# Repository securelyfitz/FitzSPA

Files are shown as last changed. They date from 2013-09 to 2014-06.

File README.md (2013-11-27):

FitzSPA
=======

Joe Fitz's Simple Power Analysis Tool

This is a simple board for monitoring power analysis of small microcontroller circuits.

See the slides from BsidesPDX here: http://goo.gl/m2waMq

## Changes
The major change in 1.1 is that there is now a 2nd potentiometer tied to the offset input of the amplifier. This allows you to dial in an offset so you can adjust to a larger differential gain without exceeding the input range of the A/D converter.

I thought i could get away without this in rev 1.0 but it has shown to be too important. Time will tell if a potentiometer is sufficient or i should have used a low impedance reference (at additional complexity, BOM cost, board space, and redesign time)

## Theory

The current across the shunt resistor Rv is measured with a differential amplifier U2. The output is digitized by the A-D converter, U1, which is triggered and synchronized by the device's own clock signal. The JP1 pins connect to a logic analyzer for sampling.

The differential amplifier will cancel out all sorts of common mode noise and only amplify the voltage across the Rv shunt resistor, which will be proportional to the instantaneous current draw of your target device. By synchronizing the A/D sampling to the device clock, we can get a digital readout at roughly the same time every clock cycle and not have to oversample 10x or more. Right now the Logic analyzer connection is asynchronous, but that should be fixed in future revisions.

Future versions will integrate a Cypress EZ-usb FX2 logic analyzer and power regulation, but they were excluded to reduce time and complexity for revision 1.x

##Using

Connect the logic analyzer to the J1 connector. Pin1 in the upper left is AD0, the LSB. The bottom two pins are both ground. If you have an 8-bit logic analyzer, start with the 8 MSBs, and if all of your sampling is in the same range, try connecting to less significant pins for higher gain.

Power +5vdc can come from a USB cable, an external supply, your logic analyzer, or from your target system

JP3 has a number of pins for various ways of connecting your shunt resistor and powering your target. Pins in order: VCC  Rv+  Rv-  GND  GND  CLK

To measure with a shunt on VCC, power supplied by FitzSPA:
* Connect VCC and Rv+ with a jumper
* Connect RV- to your target board's VCC
* Connect GND to your target board's GND
* Connect CLK to your target board's CLK

To measure with a shunt on GND, power supplied by FitzSPA:
* Connect VCC to your target board's VCC
* Connect Rv+ to your target board's ground
* Connect RV- and GND with a jumper
* Connect CLK to your target board's CLK

To measure with a shunt on VCC, with a separate external supply:
* Connect Rv+ to the external supply
* Connect RV- to your target board's VCC
* Connect GND to your target board's GND and external supply GND
* Connect CLK to your target board's CLK

To measure with a shunt on GND, power supplied by FitzSPA:
* Connect your external supply to the target board's VCC
* Connect Rv+ to your target board's ground
* Connect RV- and GND with a jumper
* Connect the second GND pin to the external supply's GND
* Connect CLK to your target board's CLK

Fire up your logic analyzer, turn on your board, and you should see the live power consumption updated each clock cycle!

##Building
Rev 1.1 is functional and continues to iron out some kinks. There are a few options for building out your board:

#### Differential Amplifier:
The AD8129 should provide much higher gains for more sensitive readings. However, I still haven't debugged why the AD8130 works fine and the AD8129 does not at G=10. For the time being, use the x30 unless you want to help the debug effort. the x29 is digikey AD8129ARMZ-ND
#### Gain setting circuit:
The gain of the differential amplifier is 1+(Rf/Rg). The default BOM uses 1k Ohm/100 Ohm, but you can vary this, or replace Rf with a potentiometer, such as digikey 987-1155-ND
####Voltage Regulator Load:
the 5v to +-12v regulator needs a minimum load to work properly. I haven't needed them, but populating R1 and R2 with 2.4k ohm resistors should provide the required load. digikey RMCF0603FT2K40CT-ND

####For the basic build you probably want:

Component | Description | Value | notes | Digikey | Price
--- | --- | --- | --- | --- | ---
U1 | AD9200ARZ | 20msps 10-bit A/D converter | | AD9200ARSZ-ND | 5.83
U2 | AD8130ARMZ | differential amplifier | AD8129 - unresolved issues. use AD8130 for now | AD8130ARMZ-ND | 4.06
U3 | VAT1-S5-D12-SMT | 5v to +-12v converter | | 102-1386-1-ND | 5.51
JP1 | 2x6 .1" header | | connects to LA | S1012EC-40-ND	| 0.51
JP2 | 1x3 .1" header | | connects ot power/ground | same as jp1 |
JP3 | 1x6 .1" header | | connects ot DUT | same as jp1 |
C1,C2,C3,C4,C5,C6,C7,C8 | 0603 SMT Capacitor | .1uF | | 587-1240-1-ND	| 0.10
C11,C12,C13,C14,C15,C16 | 0805 SMT Capacitor | 10uF | doesn't need to be electrolytic | 587-1295-1-ND | 0.25
R1,R2 | 0603 SMT resistor |  | leave empty unless needed to stabilize +-12v output |
R3 | 0603 SMT resistor | 150 ohm | LED series resistor | RMCF0603FT150RCT-ND | 0.04
R4 | 0603 SMT resistor | 10 ohm | provides a little isolation between digital and analog VCC | RMCF0603FT10R0CT-ND | 0.04
Rv | 0603 SMT resistor | 1 ohm | shunt resistor - DUT power crosses over this | RMCF0603FT1R00CT-ND	| 0.04 
Rg | 0603 SMT resistor | 100 ohm | gain resistor | RMCF0603FT100RCT-ND | 0.04
Rf1 | 0603 SMT resistor | 1k ohm | gain resistor | RMCF0603FT1K00CT-ND | 0.04
Rf | 84WR SMT Potentiometer |  | leave empty if using fixed Rf1 instead |
Rf2 | 84WR SMT Potentiometer |  | potentiometer for adjusting offset bluewire pin 4 to ground if you really don't want this |
LED | 0603 SMT LED | | | 475-2558-1-ND	| 0.09

The Digikey BOM is saved in FitzSPA-BOM.csv, you can upload or paste it's contents into the BOM wizard: https://www.digikey.com/classic/registereduser/BOMWizard.aspx

$18.50 + shipping

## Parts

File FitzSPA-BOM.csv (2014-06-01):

Digi-Key Part Number | Manufacturer | Manufacturer Part Number | Customer Reference | Quantity 1 | Quantity 2 | Quantity 3 | Description | Comments | RoHS Status | Lead Free Status | REACH Status
AD9200ARSZ-ND | ANALOG DEVICES INC | AD9200ARSZ |  | 1 | 0 | 0 | IC ADC 10BIT CMOS 20MSPS 28-SSOP | Alternate Packaging Exists | RoHS Compliant | Lead free | Unaffected May-2011
AD8130ARMZ-ND | ANALOG DEVICES INC | AD8130ARMZ |  | 1 | 0 | 0 | IC OPAMP DIFF 290MHZ 8MSOP | Alternate Packaging Exists | RoHS Compliant | Lead free | Unaffected May-2011
102-1386-1-ND | CUI INC (VA) | VAT1-S5-D12-SMT-TR |  | 1 | 0 | 0 | CONVERTER DC/DC +/-12V OUT 1W | Alternate Packaging Exists | RoHS Compliant | Lead free | Unaffected Oct-2011
S1012EC-40-ND | SULLINS CONNECTOR SOLUTIONS | PREC040SAAN-RC |  | 1 | 0 | 0 | CONN HEADER .100 inch SNGL STR 40POS |  | RoHS Compliant | Lead free | Unaffected Sep-2008
587-1240-1-ND | TAIYO YUDEN (VA) | EMK107B7104KA-T |  | 8 | 0 | 0 | CAP CER 0.1UF 16V 10% X7R 0603 | Alternate Packaging Exists | RoHS Compliant | Lead free | Unaffected Nov-2009
587-1295-1-ND | TAIYO YUDEN (VA) | EMK212BJ106KG-T |  | 6 | 0 | 0 | CAP CER 10UF 16V 10% X5R 0805 | Alternate Packaging Exists | RoHS Compliant | Lead free | Unaffected Nov-2009
RMCF0603FT150RCT-ND | STACKPOLE ELECTRONICS INC (VA) | RMCF0603FT150R |  | 1 | 0 | 0 | RES 150 OHM 1/10W 1% 0603 | Alternate Packaging Exists | RoHS Compliant | Lead free | Unaffected Aug-2011
RMCF0603FT10R0CT-ND | STACKPOLE ELECTRONICS INC (VA) | RMCF0603FT10R0 |  | 1 | 0 | 0 | RES 10 OHM 1/10W 1% 0603 | Alternate Packaging Exists | RoHS Compliant | Lead free | Unaffected Aug-2011
RMCF0603FT1R00CT-ND | STACKPOLE ELECTRONICS INC (VA) | RMCF0603FT1R00 |  | 1 | 0 | 0 | RES 1 OHM 1/10W 1% 0603 | Alternate Packaging Exists | RoHS Compliant | Lead free | Unaffected Aug-2011
RMCF0603FT100RCT-ND | STACKPOLE ELECTRONICS INC (VA) | RMCF0603FT100R |  | 1 | 0 | 0 | RES 100 OHM 1/10W 1% 0603 | Alternate Packaging Exists | RoHS Compliant | Lead free | Unaffected Aug-2011
RMCF0603FT1K00CT-ND | STACKPOLE ELECTRONICS INC (VA) | RMCF0603FT1K00 |  | 1 | 0 | 0 | RES 1K OHM 1/10W 1% 0603 | Alternate Packaging Exists | RoHS Compliant | Lead free | Unaffected Aug-2011
475-2558-1-ND | OSRAM OPTO SEMICONDUCTORS INC(VA) | LY Q976-P1S2-36 |  | 1 | 0 | 0 | LED CHIPLED 587NM YLW 0603 SMD | Alternate Packaging Exists | RoHS Compliant | Lead free | Unaffected Aug-2011
987-1155-ND | TT ELECTRONICS/BI | 84WR10KLF |  | 2 | 0 | 0 | TRIMMER 10K OHM 0.25W SMD |  | RoHS Compliant | Lead free | Unaffected Jun-2011

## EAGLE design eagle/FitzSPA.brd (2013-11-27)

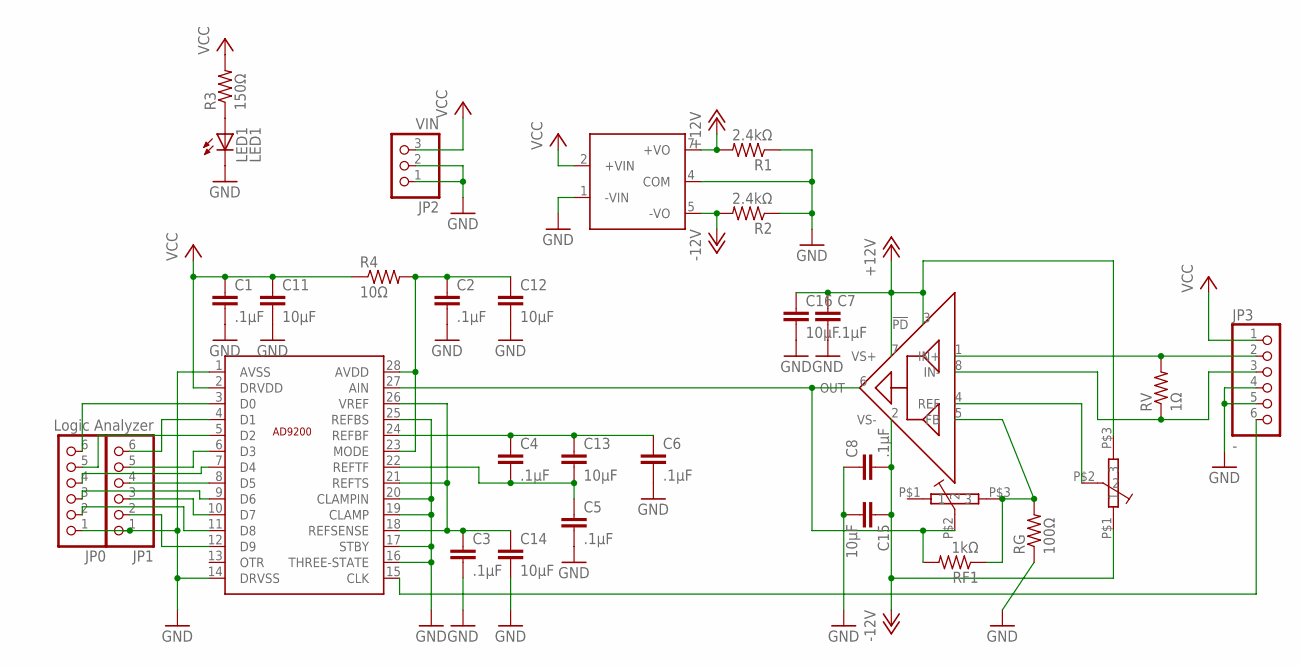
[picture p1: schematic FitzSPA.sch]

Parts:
C1, C2, C3, C4, C5, C6, C7, C8: .1µF; C0603
C11, C12, C13, C14, C15, C16: 10µF; C0805
JP0: 1X06-BIGLOCK
JP1: Logic Analyzer; 1X06-BIGLOCK
JP2: VIN; 1X03
JP3: -; 1X06-BIGLOCK
LED1: LED1; CHIPLED_0603
R1, R2: 2.4kΩ; R0603
R3: 150Ω; R0603
R4: 10Ω; R0603
RF, RF2: 10kΩ; MODEL84POT
RF1: 1kΩ; R0603
RG: 100Ω; R0603
RV: 1Ω; R0603
U1: AD9200ARZ; SSOP28
U2: AD8129ARMZ; MSOP8
U3: VAT1-SMT

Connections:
+12V: C7.1, C16.1, R1.2, RF2.P$3 (3), U2.3 (!PD), U2.7 (VS+), U3.7 (+VO)
-12V: C8.2, C15.1, R2.2, RF2.P$1 (1), U2.2 (VS-), U3.5 (-VO)
GND: C1.2, C2.2, C3.2, C5.2, C6.2, C7.2, C8.1, C11.2, C12.2, C14.2, C15.2, C16.2, JP0.1, JP1.1, JP2.1, JP2.2, JP3.4, JP3.5, LED1.C, R1.1, R2.1, RG.1, U1.1 (AVSS), U1.14 (DRVSS), U1.16 (THREE-STATE), U1.17 (STBY), U1.19 (CLAMP), U1.20 (CLAMPIN), U1.25 (REFBS), U3.1 (-VIN), U3.4 (COM)
unnamed: RF.P$2 (2), RF1.2, U1.27 (AIN), U2.6 (OUT)
unnamed: JP1.6, U1.4 (D1)
unnamed: RF.P$3 (3), RF1.1, RG.2, U2.5 (FB)
unnamed: C4.1, C6.1, C13.1, U1.24 (REFBF)
unnamed: JP1.5, U1.6 (D3)
unnamed: JP3.3, RV.1, U2.8 (IN-)
unnamed: C4.2, C5.1, C13.2, U1.22 (REFTF)
unnamed: C3.1, C14.1, U1.18 (REFSENSE), U1.21 (REFTS), U1.26 (VREF)
unnamed: JP1.4, U1.8 (D5)
unnamed: JP1.3, U1.10 (D7)
unnamed: JP1.2, U1.12 (D9)
unnamed: JP0.6, U1.3 (D0)
unnamed: JP0.5, U1.5 (D2)
unnamed: JP0.4, U1.7 (D4)
unnamed: JP0.3, U1.9 (D6)
unnamed: JP0.2, U1.11 (D8)
unnamed: LED1.A, R3.1
unnamed: JP3.2, RV.2, U2.1 (IN+)
unnamed: JP3.6, U1.15 (CLK)
unnamed: C2.1, C12.1, R4.2, U1.23 (MODE), U1.28 (AVDD)
unnamed: RF2.P$2 (2), U2.4 (REF)
VCC: C1.1, C11.1, JP2.3, JP3.1, R3.2, R4.1, U1.2 (DRVDD), U3.2 (+VIN)

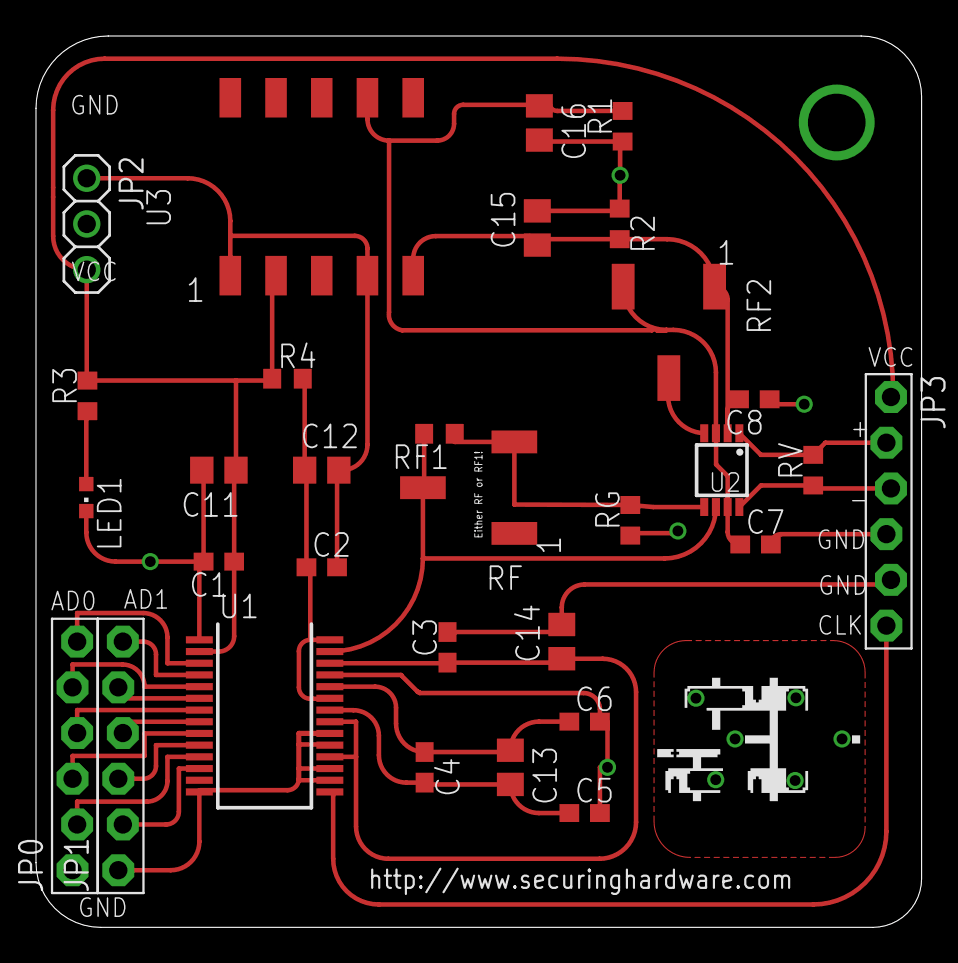
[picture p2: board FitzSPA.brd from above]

Board: 2 copper layers, 49.2 x 49.5 mm, 33 parts (1 on the bottom side), 25 nets.

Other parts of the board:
U$4: SH-HALFINCH
U$5: SECURINGHARDWAREDOTCOM

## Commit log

2013-09-23 Update README.md
    added BOM parts in a table
2013-09-23 Update README.md
    Fill in parts, BOM detail, basic documentation and wiring instructions
2013-09-23 Added eagle, libraries, gerbers
    [FitzSPA10.brd, FitzSPA10.sch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]
2013-11-27 Moving to branches for revisions instead of file names
    changed filename
    added 2nd POT on pin 4 of the diff amp to give a variable offset
    [FitzSPA.brd, FitzSPA.sch]
2013-11-27 Fixing filenames, new revision
    shortened filenames
    removed version number from filename
    gerbers for version 1.1
    [FitzSPA.GBL, FitzSPA.GBO, FitzSPA.GBS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]
2013-12-13 initial version for FitzSPA 1.0
    [FitzSPA-BOM.csv]
2013-12-13 added potentiometers for version 1.1
    [FitzSPA-BOM.csv]
